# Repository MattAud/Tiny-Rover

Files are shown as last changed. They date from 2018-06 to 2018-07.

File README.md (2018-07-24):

# Tiny-Rover
A modification of Adafruit's  Trinket Powered Rover to function as a tabletop scale RC tank

The Adafruit Trinket Rover ( https://learn.adafruit.com/trinket-powered-rover/red-rover ) is a cool starter project. The only drawback is that the treads are those woven wrist bands and I can't find them cheaply. I've created a replacement drive wheel and idler that mimic the same design, but instead take standard silicone wrist bands that are readily available on online retailers like Amazon.

These wrist bands are typically available in two sizes- youth (7 in) and adult (8 in). I have only tried this with the YOUTH size. If you try this with the adult size, your mileage may vary.

# Tiny-Tank

The other part of this is that I want to make a small, cheap RC tank. 

It will be powered by an Arduino Mini Pro (since I have ~10 laying around). I'm using the 5v variant. It will have a laser cannon that will fire and light sensors that will detect hits from enemy tanks. It will also have a buzzer for sound effects and indicator LEDs to show have many lives the tank still has.

The TX/RX is the super cheap, 4 channel RF modules available on eBay/Amazon for dirt cheap. I shose them for their cheapness and the ability to set the channels on them.

The light sensors are your typical photoresistors that are "extended" through straws. When the straws have a laser shone on them at 3", there is still a noticible jump in the code's analog reading.

The first iteration was tested and works! The only problems still are mechanical with the chassis throwing track.

The second iteration of the board was designed and ordered.

# Problems to still troubleshoot:

- The continuous diameter of the drive wheel and idler cause the tank to throw track. Aaron suggested adding a bevel on the inside.

- Board schematic MkII is in! It includes an on/off switch, is smaller in size, and has solder points for AA/AAA battery packs OR a 2cell, 7.4v lipo battery.

- The trimpot can be used to adjust the sensitivity of the light sensor threshold. An alternative could be that during the setup loop a number of measurements are taken and averaged.

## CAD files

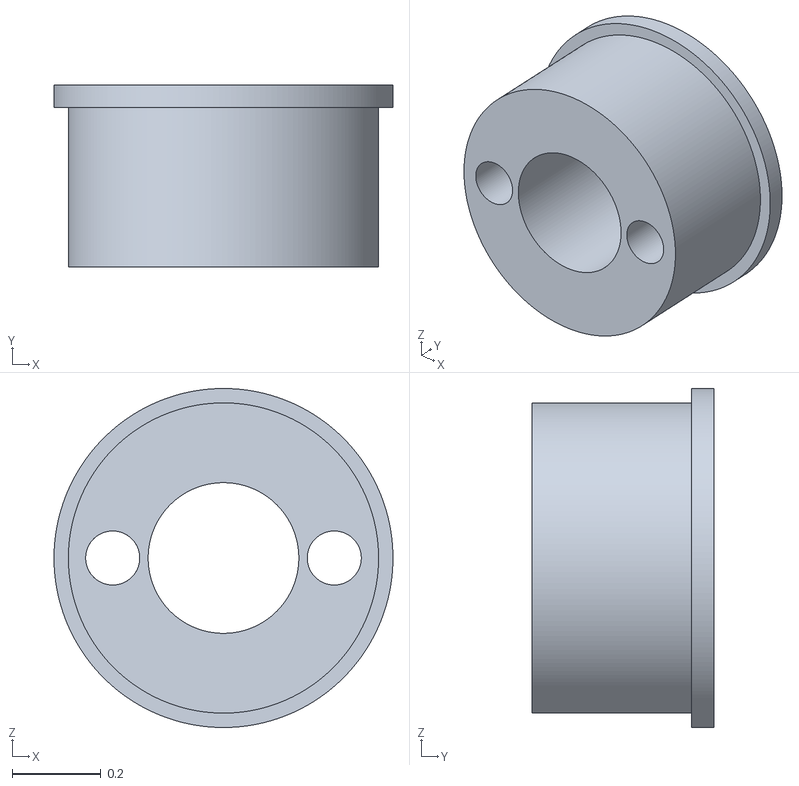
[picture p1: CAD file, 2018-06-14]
Drive Wheel Outside.stl
0.765 x 0.41 x 0.765

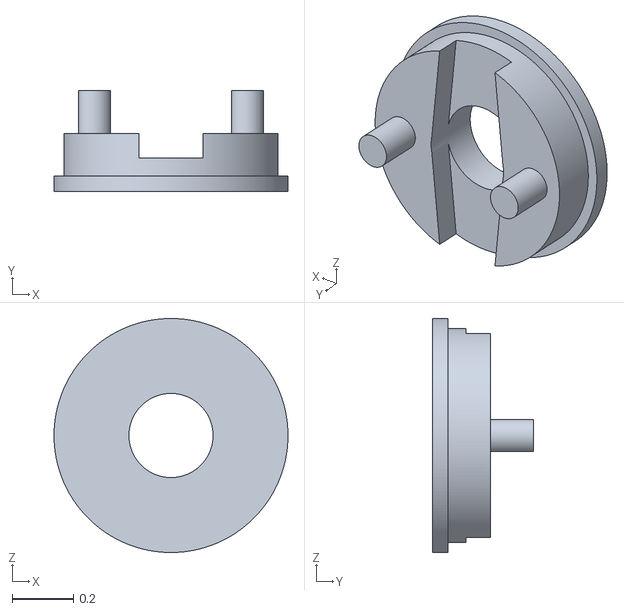
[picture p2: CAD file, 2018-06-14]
Drive Wheel Inside.stl
0.765 x 0.33 x 0.765

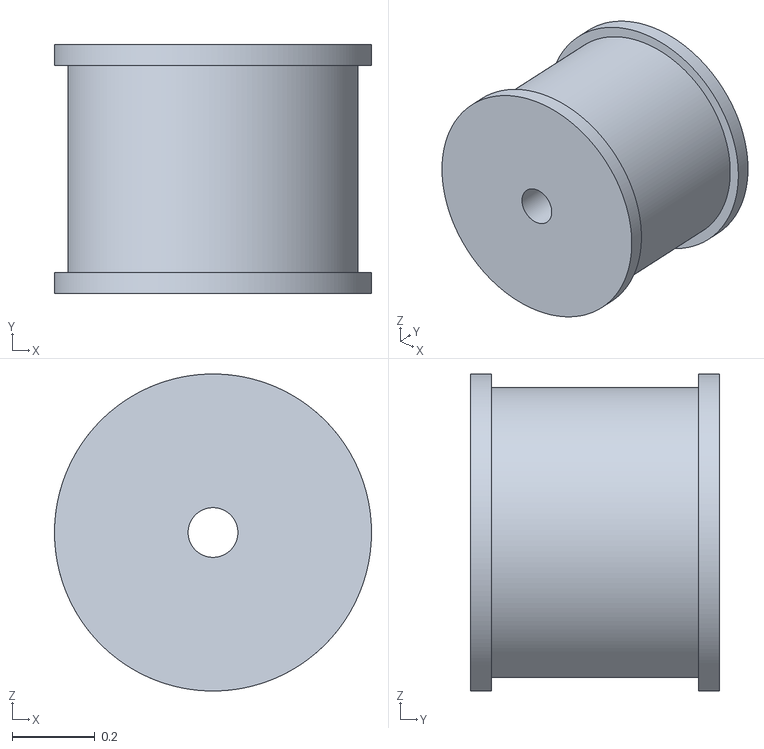
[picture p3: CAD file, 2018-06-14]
Idler Wheel.stl
0.765 x 0.6 x 0.765

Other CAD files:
Drive Wheel.f3d
Idler Wheel.f3d

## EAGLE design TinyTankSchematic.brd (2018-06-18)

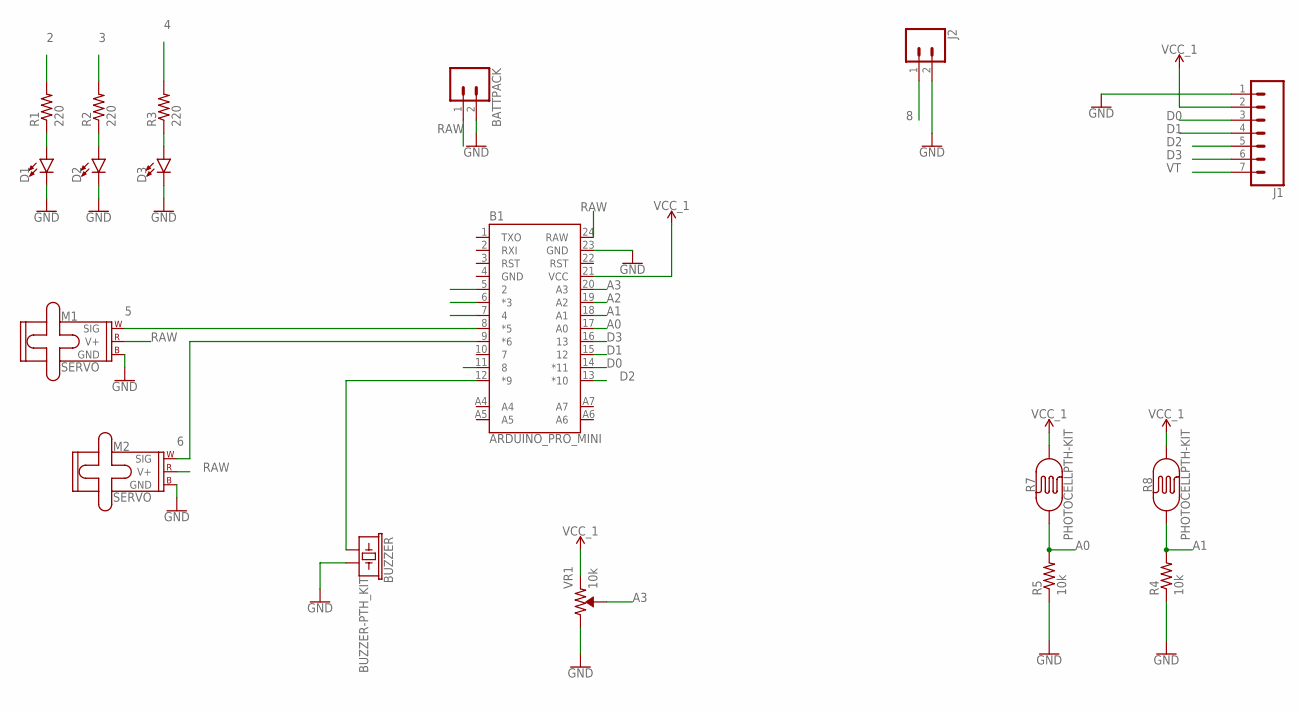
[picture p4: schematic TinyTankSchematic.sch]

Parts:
B1: ARDUINO_PRO_MINI
BATTPACK: CONN_02POLAR; MOLEX-1X2
BUZZER: BUZZER-PTH_KIT; BUZZER-12MM-KIT
D1, D2, D3: LED5MM; LED_5MM
J1: CONN_07; 1X07
J2: CONN_02PTH3; 1X02_LONGPADS
M1, M2: SERVO; 1X03
R1, R2, R3: 220; 0204/7
R4, R5: 10k; 0204/7
R7, R8: PHOTOCELLPTH-KIT; PHOTOCELL-KIT
VR1: 10k; TRIMPOT-PTH-3386U

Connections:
2: B1.5 (2), R1.2
3: B1.6 (*3), R2.2
4: B1.7 (4), R3.2
5: B1.8 (*5), M1.1 (SIG)
6: B1.9 (*6), M2.1 (SIG)
8: B1.11 (8), J2.1
A0: B1.17 (A0), R5.2, R7.1
A1: B1.18 (A1), R4.2, R8.1
A2: B1.19 (A2)
A3: B1.20 (A3), VR1.2 (WIPER)
D0: B1.14 (*11), J1.3
D1: B1.15 (12), J1.4
D2: B1.13 (*10), J1.5
D3: B1.16 (13), J1.6
GND: B1.4 (GND), B1.23 (GND), BATTPACK.2, BUZZER.- (2), D1.K (C), D2.K (C), D3.K (C), J1.1, J2.2, M1.3 (GND), M2.3 (GND), R4.1, R5.1, VR1.3 (CW)
unnamed: D1.A, R1.1
unnamed: D2.A, R2.1
unnamed: D3.A, R3.1
unnamed: B1.12 (*9), BUZZER.+ (1)
RAW: B1.24 (RAW), BATTPACK.1, M1.2 (V+), M2.2 (V+)
VCC_1: B1.21 (VCC), J1.2, R7.2, R8.2, VR1.1 (CCW)
VT: J1.7

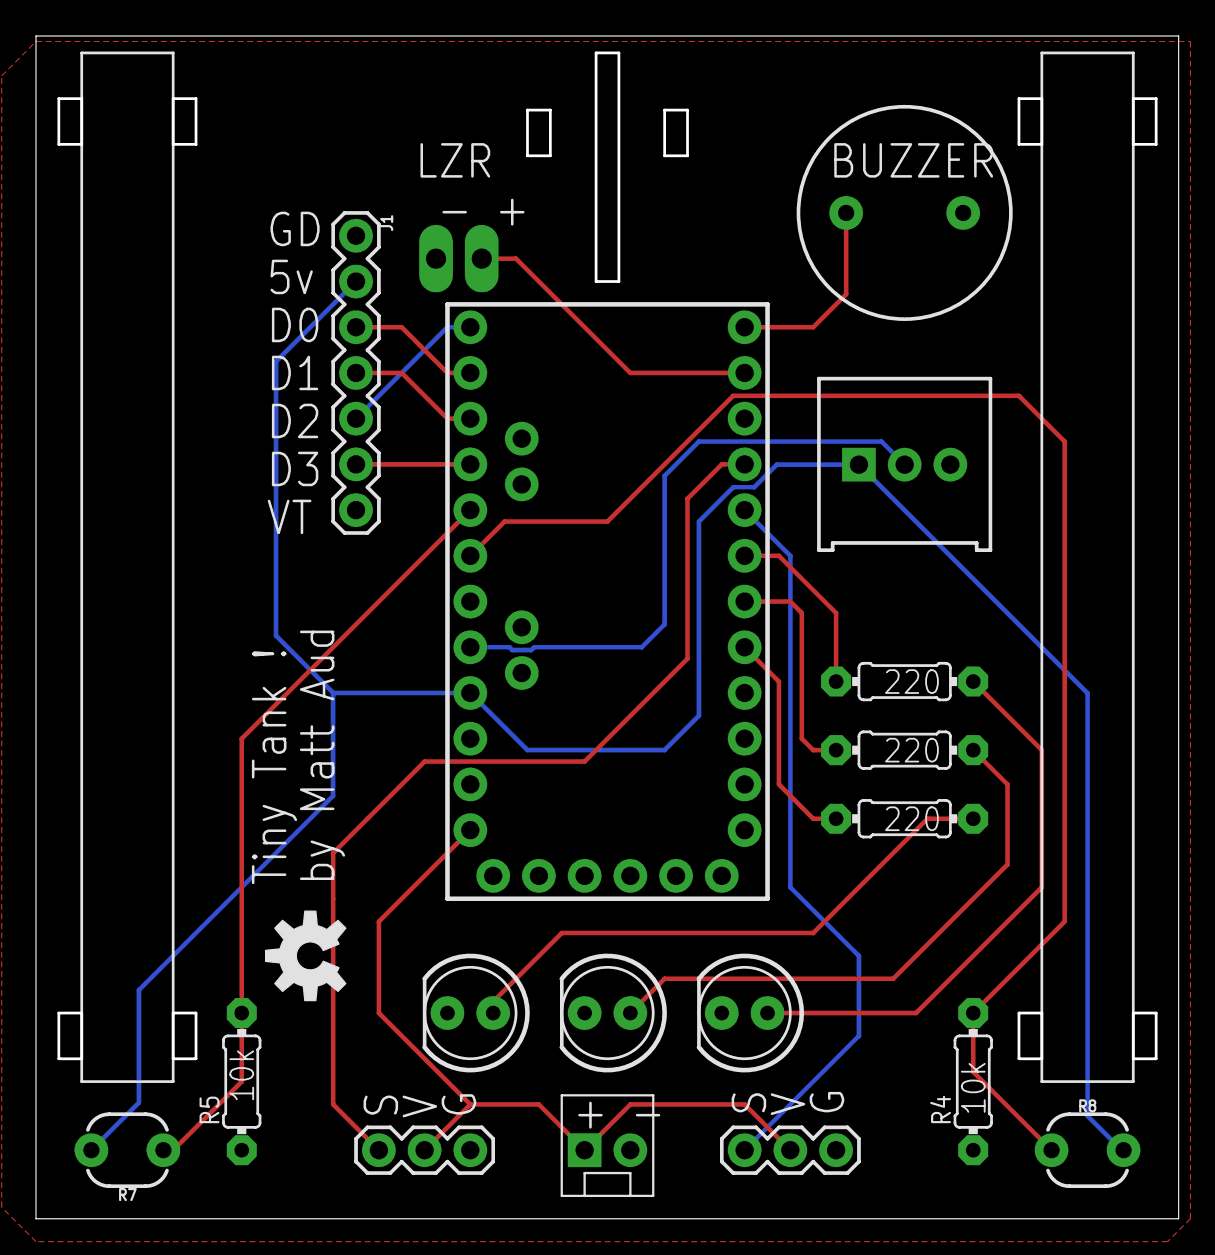
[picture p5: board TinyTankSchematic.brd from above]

Board: 2 copper layers, 63.5 x 65.7 mm, 19 parts (0 on the bottom side), 20 nets.

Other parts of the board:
U$1: OSHW-LOGO-M

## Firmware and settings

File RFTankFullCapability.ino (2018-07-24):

/* This is the next iteration in the code after RFTankStripDown.
 * StripDown took the partial code and made it faster in order to decrease the stutter
 * and give a proof of concept. It was, however, still partial.
 * 
 * This code adds in the "rest" of the tank's features that are
 * mounted on the PCB:
 * -All 3 life LEDs (and lives)
 * -Both light sensors
 * -The potentiometer to adjust the sensitivity of the light sensors.
 * 
 * Last update: 20180710
 * 
 * To Do:
 * 
 * -Impliment fwd/back/stop vals?
 * -When you die, stay dead
 * -More songs?
 * -better steering
 * -Scroll lights in the set up?
 * 
 */

#include <Servo.h>
 //pins
int buzzer = 9;
int laser = 8;
int lifeLED1 = 2;
int lifeLED2 = 3;
int lifeLED3 = 4;

Servo leftServo;
Servo rightServo;

int center = 90;
int fwd = 120;
int back = 50;

// radio inputs
int A = 10;
int B = 11;
int C = 13;
int D = 12;

int lightSensorL = A0;
int lightSensorR = A1;
int sensorValueL = 0;
int sensorValueR = 0;
int potentiometer = A3;

int life = 3;
int wait = 20;
int threshold = 650;

int a = 0;
int b = 0;
int c = 0;
int d = 0;



void setup() {
  pinMode(buzzer, OUTPUT);
  pinMode(lifeLED1, OUTPUT);
  pinMode(lifeLED2, OUTPUT);
  pinMode(lifeLED3, OUTPUT);
  pinMode(laser, OUTPUT);

  leftServo.attach(5);
  rightServo.attach(6);

  pinMode(A, INPUT);
  pinMode(B, INPUT);
  pinMode(C, INPUT);
  pinMode(D, INPUT);

  Serial.begin(9600);
}

void loop() {
  while(life > 0){
    Serial.println("In the life loop!");

    Serial.println("Read the trimpot:");
    threshold = analogRead(potentiometer);
    Serial.println(threshold);
    
    sensorValueL = analogRead(lightSensorL);
    sensorValueR = analogRead(lightSensorR);
    Serial.println(sensorValueL);
    Serial.println(sensorValueR);
    
    if(sensorValueL < threshold && sensorValueR < threshold) {
      Serial.println("In the if loop!");

      a = digitalRead(A);
      b = digitalRead(B);
      c = digitalRead(C);
      d = digitalRead(D);
      
      Serial.println(a);
      Serial.println(b);
      Serial.println(c);
      Serial.println(d);
      delay(wait);
      
      //one button == drive
      if(a == 1 && b ==0 && c == 0 && d ==0){//(b && c && d == 0 )){
        Serial.println("A LOOP===================");
        leftServo.write(10);
        delay(wait);
      }
      if(a == 0 && b ==1 && c == 0 && d ==0){//(b == HIGH && (a && c && d == LOW )){
        Serial.println("B LOOP===================");
        leftServo.write(10);
        rightServo.write(150);
        delay(wait);
      }
      if(a == 0 && b ==0 && c == 1 && d ==0){//(c == HIGH && (a && b && d == LOW )){
        Serial.println("C LOOP===================");
        leftServo.write(170);
        rightServo.write(30);
        delay(wait);
      }
      if(a == 0 && b ==0 && c == 0 && d ==1){//(c == HIGH && (a && b && d == LOW )){
        Serial.println("D LOOP===================");
        rightServo.write(150);
        delay(wait);
      }

      delay(wait);

      //two buttons == shoot
      if(a && b == 1 || c && d == 1 || a && c == 1 || b && d == 1 ){
        digitalWrite(laser, HIGH);
        // BA-DOOM!
        tone(buzzer, 75);
        delay(150);
        tone(buzzer, 50);
        delay(100);
        noTone(buzzer);
        delay(250);
        digitalWrite(laser, LOW);
      }

      // no buttons == stop
      if(a ==0 && b ==0  && c == 0 && d == 0){
        Serial.println("~~~~~~~~~~~~~~~~~~~~~~~~~~~~~~~~~~~~~~~~~~~~~~~~~~");
        leftServo.write(90);
        rightServo.write(90);
      }
    }// if sensor  value < threshold
    
    else {//sensorValue is > threshold, life a life:
      life = life-1;
      tone(buzzer, 50);
      delay(900);
      noTone(buzzer);
      delay(100);
    }

    // assign life lights:
    switch (life) {
      case 3:
        digitalWrite(lifeLED1, HIGH);
        digitalWrite(lifeLED2, HIGH);
        digitalWrite(lifeLED3, HIGH);
        break;
      case 2:
        digitalWrite(lifeLED1, HIGH);
        digitalWrite(lifeLED2, HIGH);
        digitalWrite(lifeLED3, LOW);
       break;
      case 1:
        digitalWrite(lifeLED1, HIGH);
        digitalWrite(lifeLED2, LOW);
        digitalWrite(lifeLED3, LOW);
       break;
      case 0:
        digitalWrite(lifeLED1, LOW);
        digitalWrite(lifeLED2, LOW);
        digitalWrite(lifeLED3, LOW);
        for(int i = 50; i <75; i++){
          tone(buzzer, i);
          delay(20);
        }
     } //switch life
 }// while live > 0

 
 //dead scenario: 
 for(int i = 75; i >50; i--){
    tone(buzzer, i);
    delay(20);
  }
  noTone(buzzer);
    delay(500);
    noTone(buzzer);
    delay(4000); 
    digitalWrite(lifeLED1, HIGH);
    digitalWrite(lifeLED2, HIGH);
    digitalWrite(lifeLED3, HIGH);
    delay(200);
    digitalWrite(lifeLED1, LOW);
    digitalWrite(lifeLED2, LOW);
    digitalWrite(lifeLED3, LOW);
    delay(200);
    life = 3;
} //loop

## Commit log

2018-06-14 3d Files for Modified Wheels
    [Drive Wheel Inside.stl, Drive Wheel Outside.stl, Drive Wheel.f3d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]
2018-06-18 Added Arduino Sketch, Eagle Files
    [TinyTankSchematic.brd, TinyTankSchematic.sch]
2018-07-11 Added RFTankFull.ino
    RFTankFull is the latest Arduino sketch. It is still not at full capacity. See the internal notes for the rundown of what still needs to change.
2018-07-24 Full capability Tank arduino sketch

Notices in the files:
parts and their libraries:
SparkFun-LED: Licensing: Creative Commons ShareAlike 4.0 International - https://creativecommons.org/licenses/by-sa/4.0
